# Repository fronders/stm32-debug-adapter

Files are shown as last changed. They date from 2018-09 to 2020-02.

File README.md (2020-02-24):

View this project on [CADLAB.io](https://cadlab.io/project/2519). 

# STM32 Debug Adapter Board

Adapter for various SWD programmers for STM32. 


<br />


This repo contains:
- Autodesk Eagle CAD v9 project
- PDF schematic & board layout
- Gerber files (in PCBWay-compatible format: RS-274X + Excellon)

What's here in README:
- [Supported STM32 programmers](#Supported-STM32-programmers)
- [Interfaces pinout](#Interfaces-pinout)
	- [Original ST-Link V2 by STMicroelectronics](#Original-ST-Link-V2-by-STMicroelectronics)
	- [J-Link by SEGGER](#J-Link-by-SEGGER)
	- [Chinese ST-Link V2 dongle](#Chinese-ST-Link-V2-dongle)
	- [Chinese MX-Link dongle](#Chinese-MX-Link-dongle)
	- [Nucleo-32 original ST-Link V2-1 by STMicroelectronics](#Nucleo-32-original-ST-Link-V2-1-by-STMicroelectronics)
	- [Nucleo-64 original ST-Link V2-1 by STMicroelectronics](#Nucleo-64-original-ST-Link-V2-1-by-STMicroelectronics)
	- [Nucleo-144 original ST-Link V2-1 by STMicroelectronics](#Nucleo-144-original-ST-Link-V2-1-by-STMicroelectronics)
	- [Blue Pill board (STM32F103C8T6)](#Blue-Pill-board-(STM32F103C8T6))
	- [Black Pill board (STM32F103C8T6)](#Black-Pill-board-(STM32F103C8T6))
	- [Tag-Connect 6 Pin Cable (TC2030-IDC)](#Tag-Connect-6-Pin-Cable-(TC2030-IDC))
- [Rev. B board info](#Rev.-B-board-info-(latest))
- [Rev. A board info](#Rev.-A-board-info)
- [Original board info](#Original-board-info)

<hr />

## Supported STM32 programmers

- Original ST-Link V2 by STMicroelectronics
- Nucleo original ST-Link V2-1 by STMicroelectronics
- Chinese ST-Link V2 clones (2 versions: ST-Link & MX-Link - different pinouts)
- J-Link by SEGGER

<hr />

## Interfaces pinout

### Original ST-Link V2 by STMicroelectronics



STM32 connector pinout:

| Name | Pin | Pin | Name |
| ---: | :---: | :---: | :--- |
| VDD_TRGT | 1 | 2 | VDD_TRGT |
| NC | 3 | 4 | GND |
| NC | 5 | 6 | GND |
| SWDIO | 7 | 8 | GND |
| SWCLK | 9 | 10 | GND |
| NC | 11 | 12 | GND |
| SWO | 13 | 14 | GND |
| NRST | 15 | 16 | GND |
| NC | 17 | 18 | GND |
| 3.3V | 19 | 20 | GND | 

### J-Link by SEGGER



Target connector pinout:

| Name | Pin | Pin | Name |
| ---: | :---: | :---: | :--- |
| 3.3V | 1 | 2 | NC |
| NC | 3 | 4 | GND |
| NC | 5 | 6 | GND |
| SWDIO | 7 | 8 | GND |
| SWCLK | 9 | 10 | GND |
| NC | 11 | 12 | GND |
| SWO | 13 | 14 | GND |
| NRST | 15 | 16 | GND |
| NC | 17 | 18 | GND |
| 5V | 19 | 20 | GND

### Chinese ST-Link V2 dongle



SWD connector pinout:

| Name | Pin | Pin | Name |
| ---: | :---: | :---: | :--- |
| RST\* | 1 | 2 | SWDIO |
| GND | 3 | 4 | GND |
| SWO\* | 5 | 6 | SWCLK |
| 3.3V | 7 | 8 | 3.3V |
| 5V\*\* | 9 | 10 | 5V\*\*

\* - not connected on the device, need to modify ST-Link: cut STM8's tracks for nRST & SWIM signals to become instead STM32's nRST (STM32 pin 18) & SWO (STM32 pin 31) signals

\*\* - not connected on adapter board

### Chinese MX-Link dongle



SWD connector pinout:

| Name | Pin | Pin | Name |
| ---: | :---: | :---: | :--- |
| RST\* | 1 | 2 | SWCLK |
| SWO\* | 3 | 4 | SWDIO |
| GND | 5 | 6 | GND |
| 3.3V | 7 | 8 | 3.3V |
| 5V\*\* | 9 | 10 | 5V\*\*

\* - not connected on the device, need to modify MX-Link: cut STM8's tracks for nRST & SWIM signals to become instead STM32's nRST (STM32 pin 18) & SWO (STM32 pin 31) signals

\*\* - not connected on adapter

### Nucleo-32 original ST-Link V2-1 by STMicroelectronics



CN2 connector pinout:

| Name | Pin | Pin | Name |
| ---: | :---: | :---: | :--- |
| - | - | 5 | NC |
| 3.3V | 4 | 3 | SWCLK |
| GND | 2 | 1 | SWDIO

### Nucleo-64 original ST-Link V2-1 by STMicroelectronics



CN4 connector pinout:

| Pin | Name |
| ---: | :--- |
| 1 | VDD_TRGT |
| 2 | SWCLK |
| 3 | GND |
| 4 | SWDIO |
| 5 | NRST |
| 6 | SWO

### Nucleo-144 original ST-Link V2-1 by STMicroelectronics



CN6 connector pinout:

| Pin | Name |
| ---: | :--- |
| 1 | VDD_TRGT |
| 2 | SWCLK |
| 3 | GND |
| 4 | SWDIO |
| 5 | NRST |
| 6 | SWO

### Blue Pill board (STM32F103C8T6)



Programming connector pinout:

| Pin | Name |
| ---: | :--- |
| 1 | GND |
| 2 | SWCLK |
| 3 | SWDIO |
| 4 | 3.3V

### Black Pill board (STM32F103C8T6)



Programming connector pinout:

| Pin | Name |
| ---: | :--- |
| 1 | GND |
| 2 | SWCLK |
| 3 | SWDIO |
| 4 | 3.3V

### Tag-Connect 6 Pin Cable (TC2030-IDC)


<br />



IDC-6 connector pinout:

| Name | Pin | Pin | Name |
| ---: | :---: | :---: | :--- |
| 3.3V | 1 | 2 | SWDIO |
| NRST | 3 | 4 | SWCLK |
| GND | 5 | 6 | SWO

<hr />

## Rev. B board info (latest)

PDF schematic & board:
- [Rev. B single file](pdf/rev.B/stm32%20debug%20adapter%20rev.B.pdf)
- [Rev. B schematic](pdf/rev.B/stm32%20debug%20adapter%20rev.B%20sch.pdf)
- [Rev. B board](pdf/rev.B/stm32%20debug%20adapter%20rev.B%20brd.pdf)

Solder jumper can be used with Original ST-Link to connect IDC-20 pin 19 VDD (3.3V) to rest of 3.3V (pins 1-2). **Jumper should remain open for use with J-Link, it has 3.3V output on pin 1, while pin 19 has 5V, might damage your board!**

Changes:
- Changed SWD pin header to match Nucleo ST-Link V2-1 pinout
- Fixed Blue Pill / Black Pill board (STM32F103C8T6) connector to be non-mirrored
- Added a solder jumper (NO) between pin 19 and pins 1-2 for Original ST-Link V2 to provide 3.3V power
- Added power indicator LED

Supported interfaces:
- Chinese ST-Link V2 dongle
- Chinese MX-Link dongle
- J-Link / Original ST-Link V2
- Tag-Connect (TC2030-IDC)
- Nucleo original ST-Link V2-1
- Blue Pill / Black Pill board

Known issues:
- none

<hr />

## Rev. A board info

PDF schematic & board:
- [Rev. A single file](pdf/rev.A/stm32%20debug%20adapter%20rev.A.pdf)
- [Rev. A schematic](pdf/rev.A/stm32%20debug%20adapter%20rev.A%20sch.pdf)
- [Rev. A board](pdf/rev.A/stm32%20debug%20adapter%20rev.A%20brd.pdf)

Changes:
- Added Blue Pill / Black Pill board (STM32F103C8T6) connector

Supported interfaces:
- Chinese ST-Link V2 dongle
- Chinese MX-Link dongle
- J-Link / Original ST-Link V2
- Tag-Connect (TC2030-IDC)
- SWD pin header
- Blue Pill / Black Pill board

Known issues:
- Blue Pill header mirrored, **need to plug in board upside down (chip facing down)**
- Original ST-Link V2 does not provide 3.3V on pins 1-2 (it is VDD_Target input instead), need to connect pin 19 to pins 1-2 on IDC-20 connector with external wire. J-Link works okay, as pin 1 has 3.3V output.

<hr />

## Original board info

PDF schematic & board:
- [Original schematic](pdf/original/stm32%20debug%20adapter%20sch.pdf)

Supported interfaces:
- Chinese ST-Link V2 dongle
- Chinese MX-Link dongle
- J-Link / Original ST-Link V2
- Tag-Connect (TC2030-IDC)
- SWD pin header

Known issues:
- Original ST-Link V2 does not provide 3.3V on pins 1-2 (it is VDD_Target input instead), need to connect pin 19 to pins 1-2 on IDC-20 connector with external wire. J-Link works okay, as pin 1 has 3.3V output.

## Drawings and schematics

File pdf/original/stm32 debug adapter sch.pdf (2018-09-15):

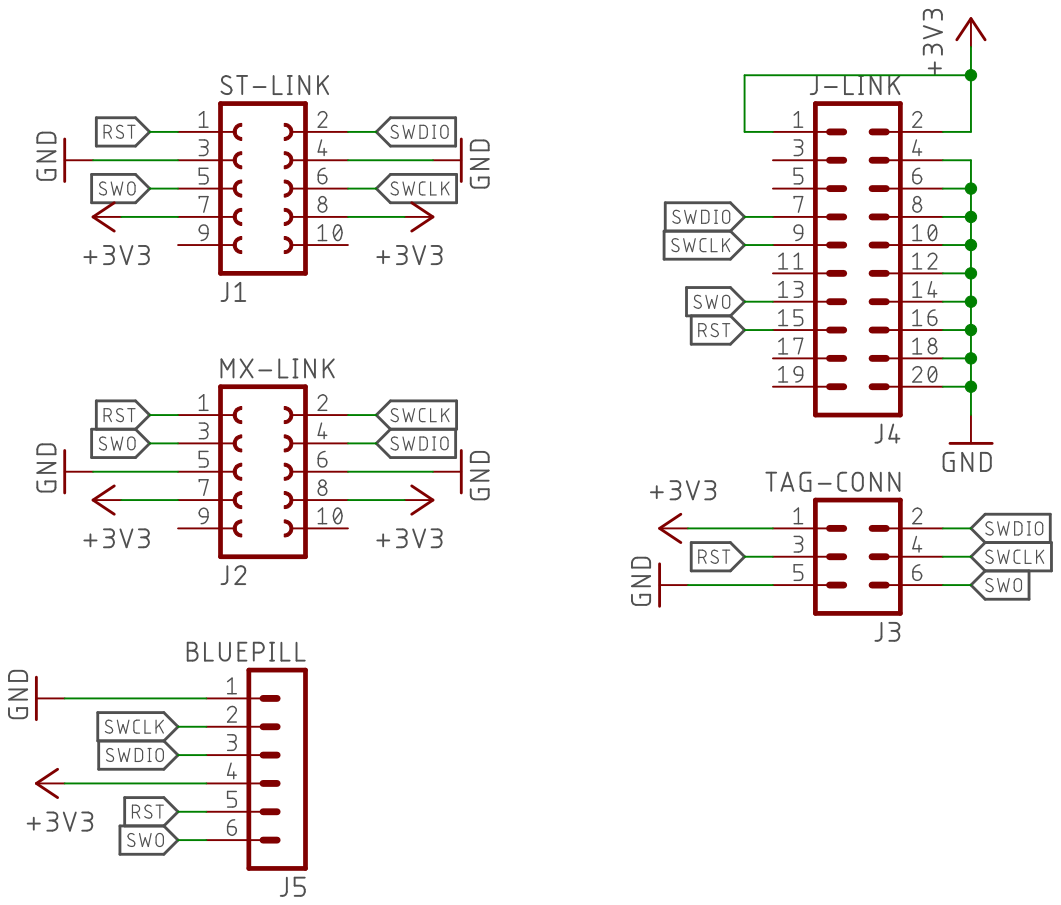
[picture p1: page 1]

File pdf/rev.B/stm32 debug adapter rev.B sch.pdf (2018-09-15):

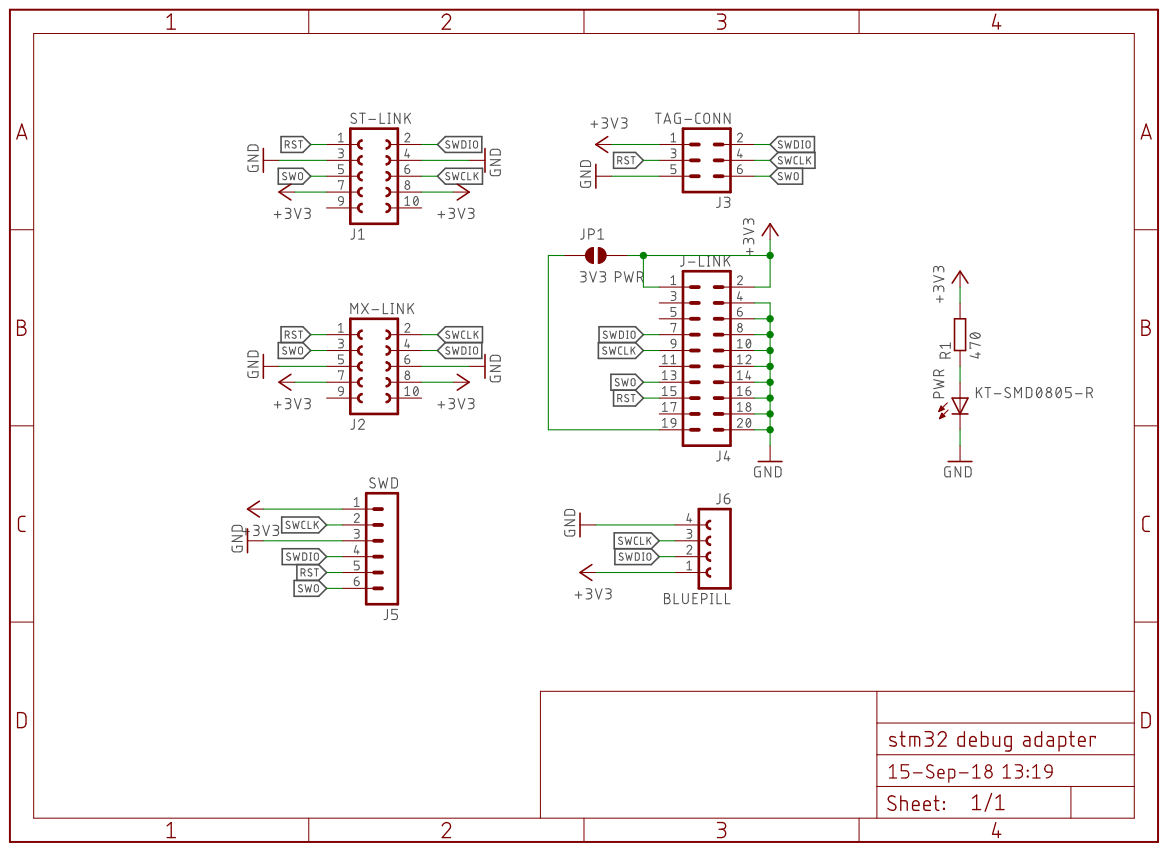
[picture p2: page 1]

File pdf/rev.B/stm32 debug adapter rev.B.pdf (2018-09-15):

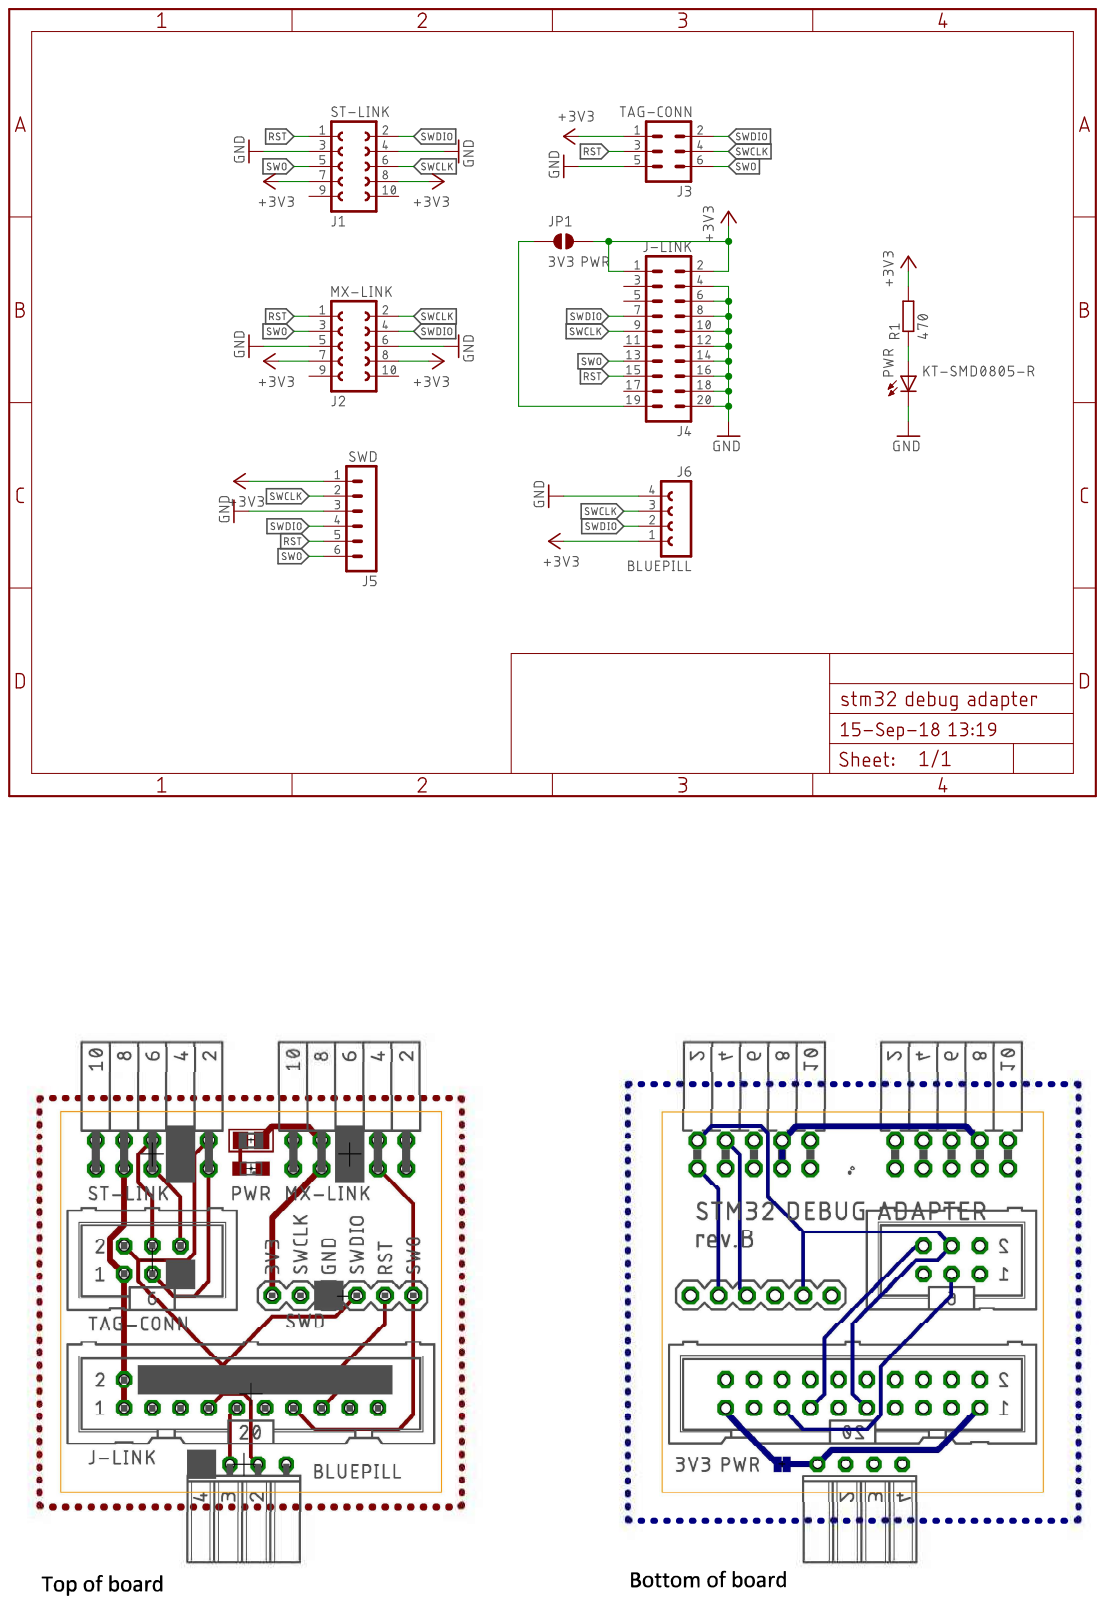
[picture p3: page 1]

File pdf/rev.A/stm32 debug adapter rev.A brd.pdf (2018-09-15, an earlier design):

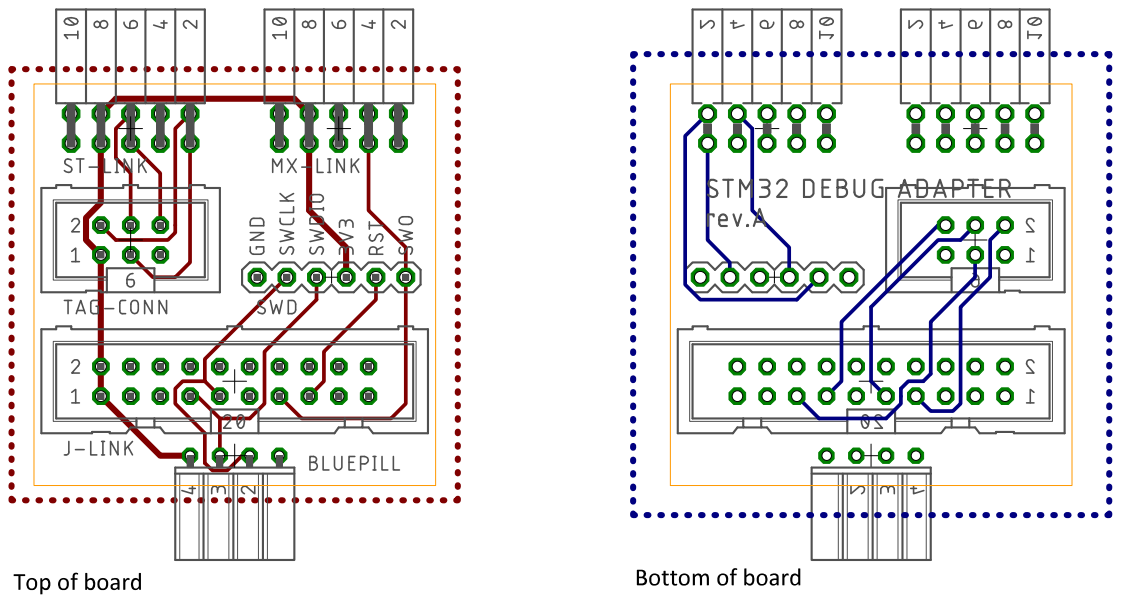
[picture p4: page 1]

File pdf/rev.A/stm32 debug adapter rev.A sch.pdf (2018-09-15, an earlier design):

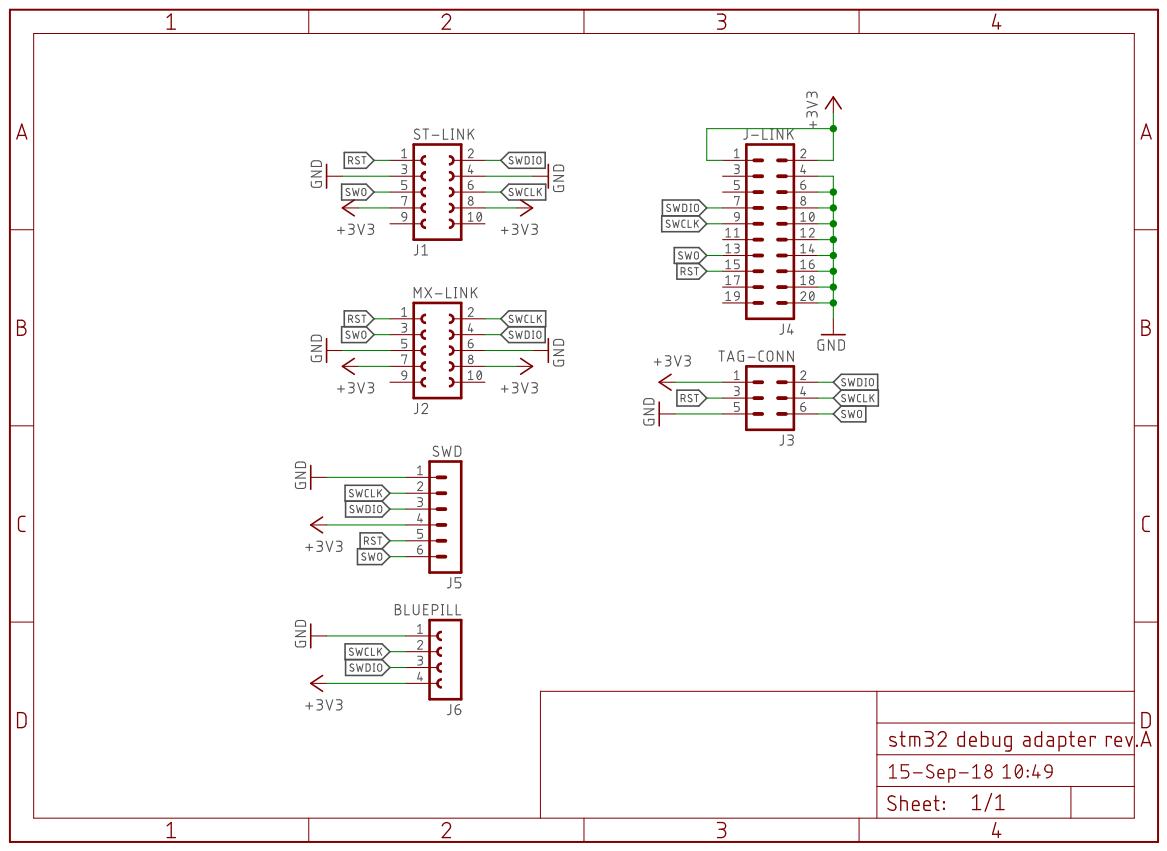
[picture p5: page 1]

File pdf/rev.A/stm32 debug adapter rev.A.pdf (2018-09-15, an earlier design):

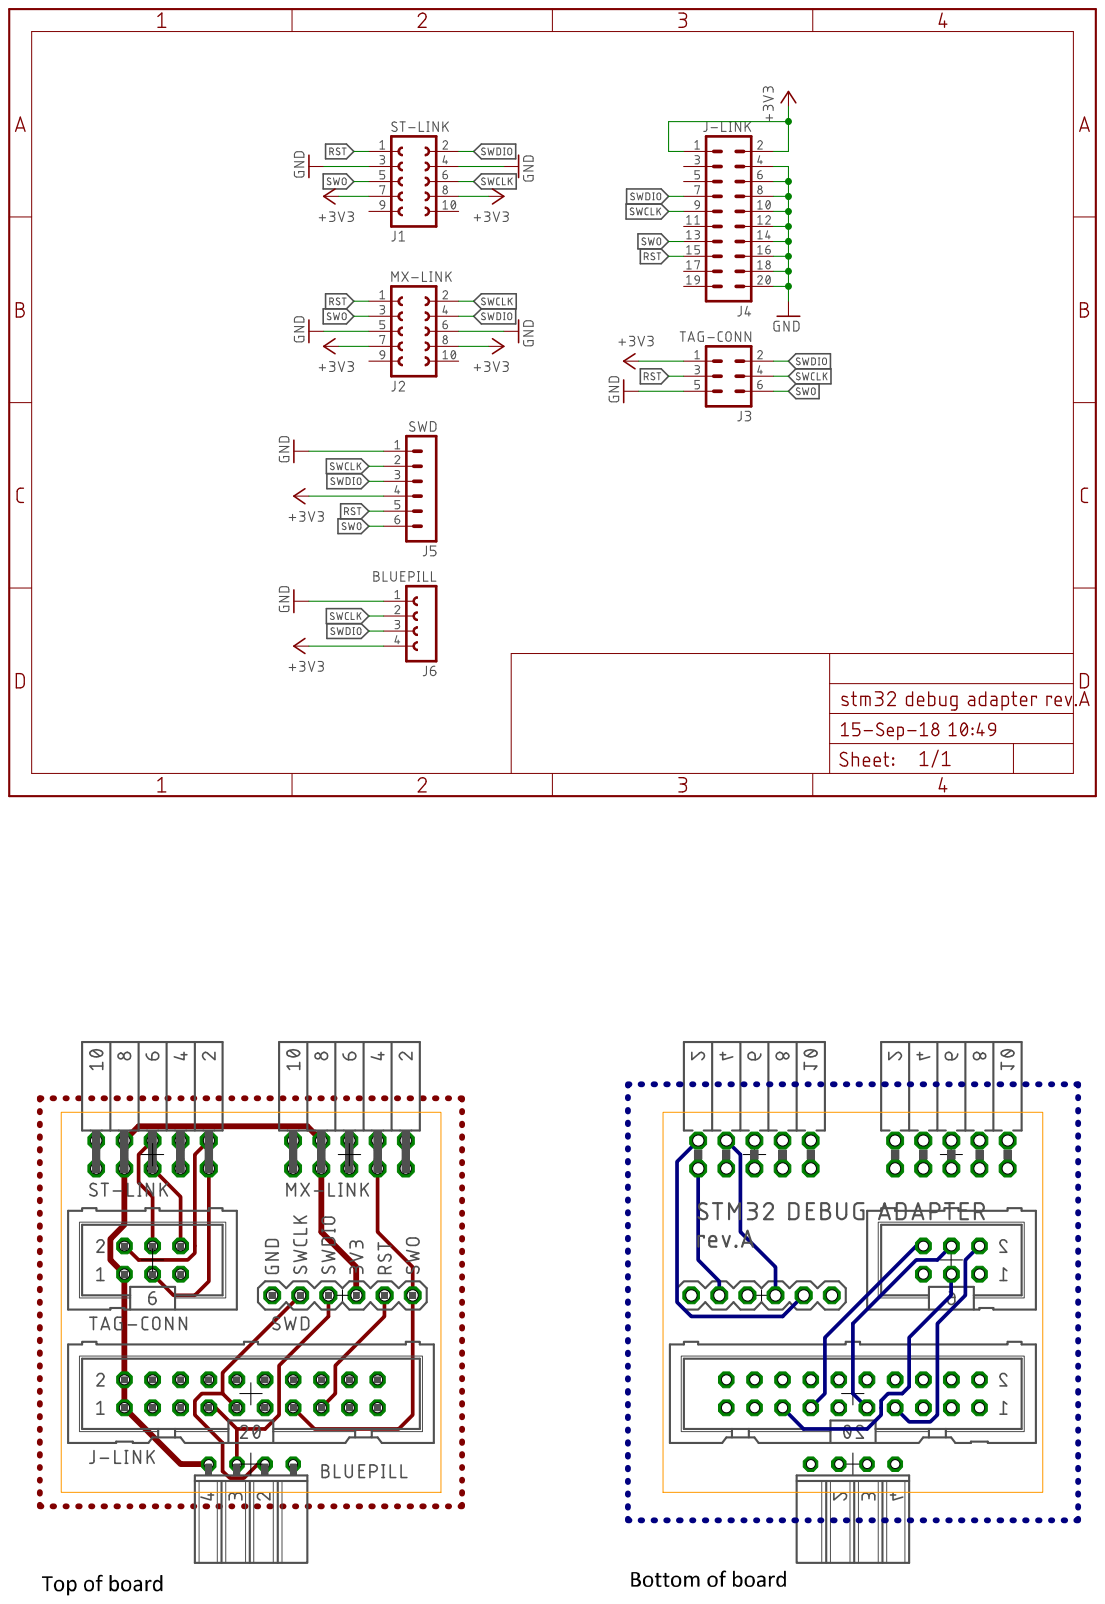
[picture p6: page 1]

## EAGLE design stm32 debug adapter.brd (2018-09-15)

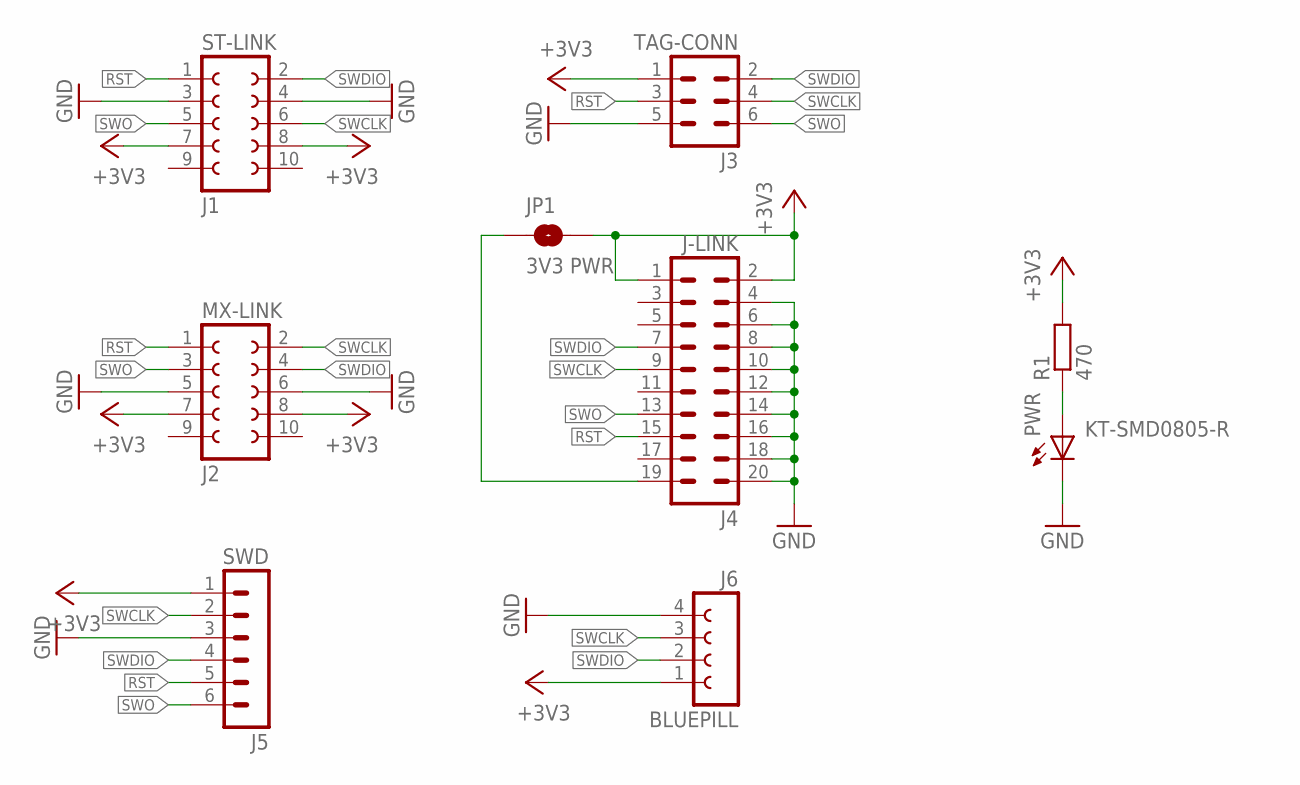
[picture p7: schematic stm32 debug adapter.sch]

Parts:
J1: ST-LINK; FE05-2W
J2: MX-LINK; FE05-2W
J3: TAG-CONN; ML6
J4: J-LINK; ML20
J5: SWD; MA06-1
J6: BLUEPILL; FE04W
JP1: 3V3 PWR; SMT-JUMPER_2_NO_NO-SILK
PWR: KT-SMD0805-R; SML0805
R1: 470; R0805

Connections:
3V3PWR: J4.19, JP1.1
+3V3: J1.7, J1.8, J2.7, J2.8, J3.1, J4.1, J4.2, J5.1, J6.1, JP1.2, R1.2
GND: J1.3, J1.4, J2.5, J2.6, J3.5, J4.4, J4.6, J4.8, J4.10, J4.12, J4.14, J4.16, J4.18, J4.20, J5.3, J6.4, PWR.C
unnamed: PWR.A, R1.1
RST: J1.1, J2.1, J3.3, J4.15, J5.5
SWCLK: J1.6, J2.2, J3.4, J4.9, J5.2, J6.3
SWDIO: J1.2, J2.4, J3.2, J4.7, J5.4, J6.2
SWO: J1.5, J2.3, J3.6, J4.13, J5.6

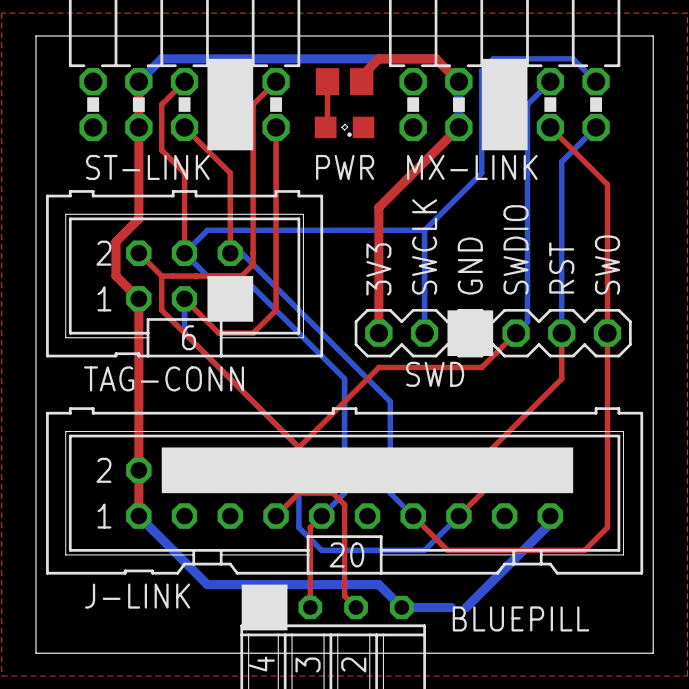
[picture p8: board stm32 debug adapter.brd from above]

Board: 2 copper layers, 34.3 x 34.3 mm, 9 parts (1 on the bottom side), 8 nets.

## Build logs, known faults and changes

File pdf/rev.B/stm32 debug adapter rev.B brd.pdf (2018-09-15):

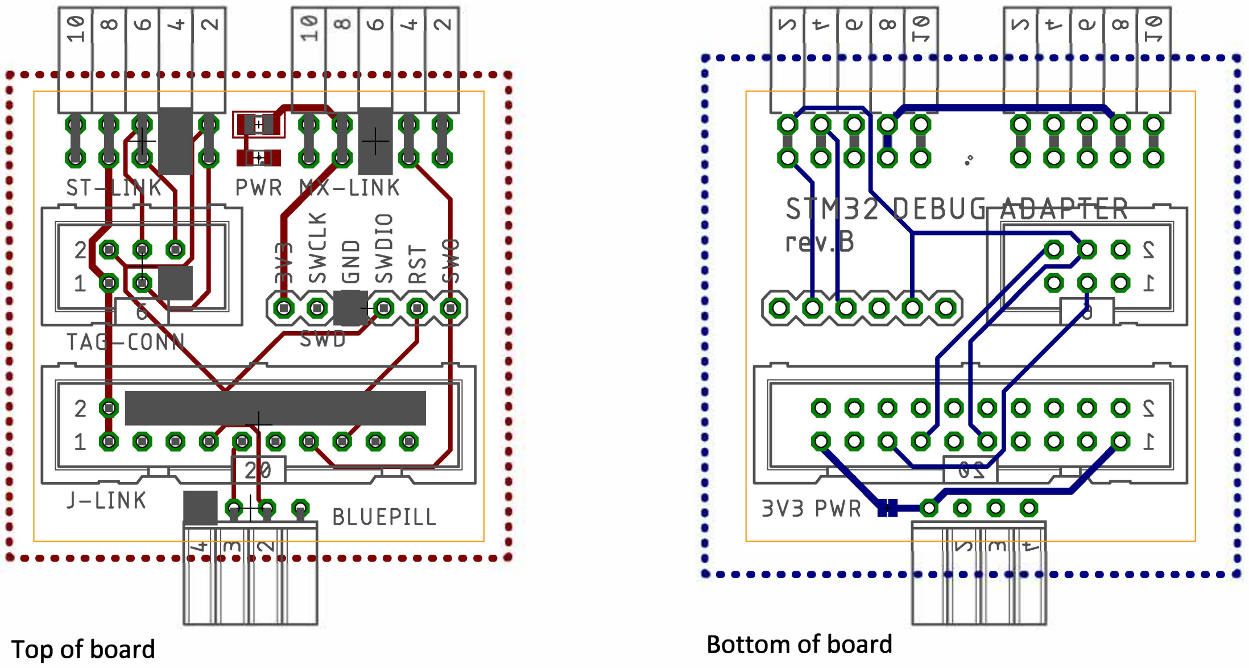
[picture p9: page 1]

••• | •••• | • | • | • | •••• | • | • | • | •••• | •••
••••••••••••• | • | • | • | ••••••••••••
Тор of board | Bottom of board

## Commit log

2018-09-15 added original schematic + gerber files
    [stm32 debug adapter.GBL, stm32 debug adapter.GBO, stm32 debug adapter.GBS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]
2018-09-15 added rev.A schematic + board + gerber + pdf files
    [stm32 debug adapter.GBL, stm32 debug adapter.GBO, stm32 debug adapter.GBS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]
2018-09-15 added rev.B schematic + board + gerber + pdf files
    [stm32 debug adapter.GBL, stm32 debug adapter.GBO, stm32 debug adapter.GBS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]
2018-09-15 updated README: board pics & pdf links

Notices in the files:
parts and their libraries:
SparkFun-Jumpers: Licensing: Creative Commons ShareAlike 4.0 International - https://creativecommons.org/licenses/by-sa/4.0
